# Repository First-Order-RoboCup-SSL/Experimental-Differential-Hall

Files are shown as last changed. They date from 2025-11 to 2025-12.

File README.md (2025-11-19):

# Experimental-Differential-Hall

PCB files for an experimental differential (dual) Hall element sensor. This PCB will attach to an STM32 which will perform processing on the output signals, so this PCB takes the Hall elements' output and ensures that the swing will use the maximum part of the 0-3V3 the STM32 can accept for SNR.

Still need to minimise resistors and power usage around our 5(?)% tolerance for resistors and then route PCB, but the amplifier (assuming $\pm$ 370mV around "ground" (2V) seems to work in LTSpice.

Takes in 3V3, GND, and 5V because the Hall element AFAIK wants $\pm$ 2V around "GND".

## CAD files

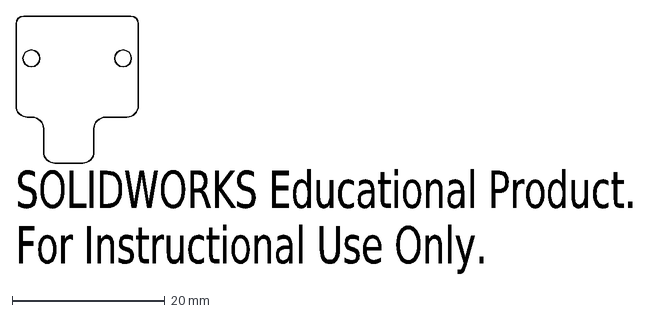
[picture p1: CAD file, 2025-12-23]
ancillary/Hall Sensor Edge Cuts 3.DXF
SOLIDWORKS Educational Product.
For Instructional Use Only.

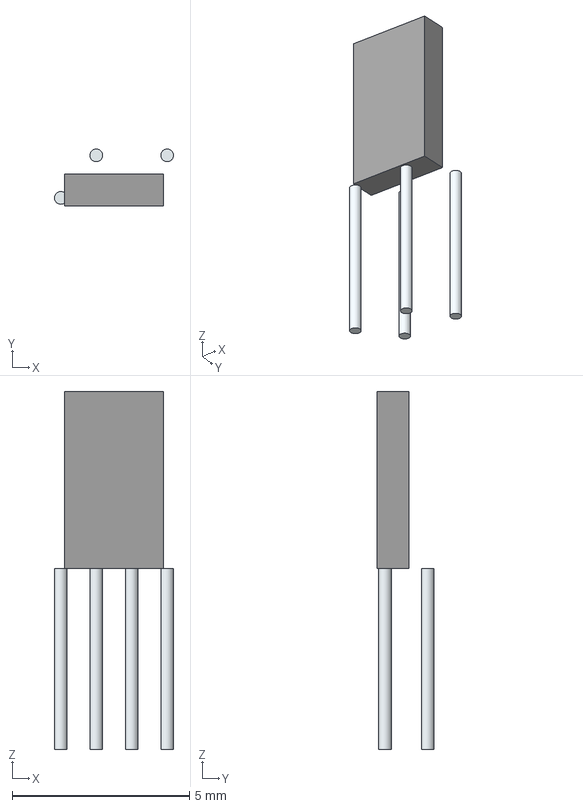
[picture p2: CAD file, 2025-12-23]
kicad/common/components/LIB_AHE300G-PA4-B/AHE300G-PA4-B/3D/AHE300G-PA4-B.stp
3.36 x 1.61 x 10.1 mm
Leads

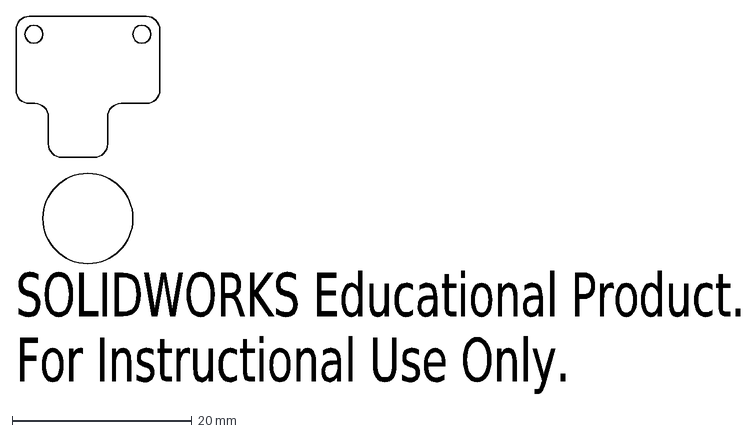
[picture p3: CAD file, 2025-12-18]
ancillary/Hall Sensor Edge Cuts 2.DXF
SOLIDWORKS Educational Product.
For Instructional Use Only.

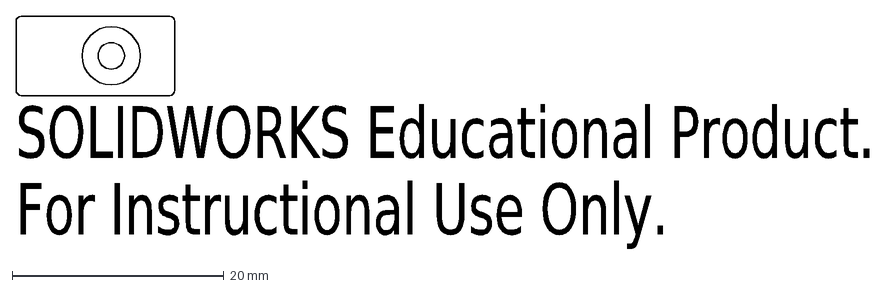
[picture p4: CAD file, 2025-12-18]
ancillary/Hall Sensor Edge Cuts 1.DXF
SOLIDWORKS Educational Product.
For Instructional Use Only.

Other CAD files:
kicad/common/components/LIB_AHE300G-PA4-B/AHE300G-PA4-B/Allegro/ahe300gpa4b.psm
kicad/common/components/LIB_AHE300G-PA4-B/AHE300G-PA4-B/DEHDL/ahe300g_pa4_b/chips/chips.prt

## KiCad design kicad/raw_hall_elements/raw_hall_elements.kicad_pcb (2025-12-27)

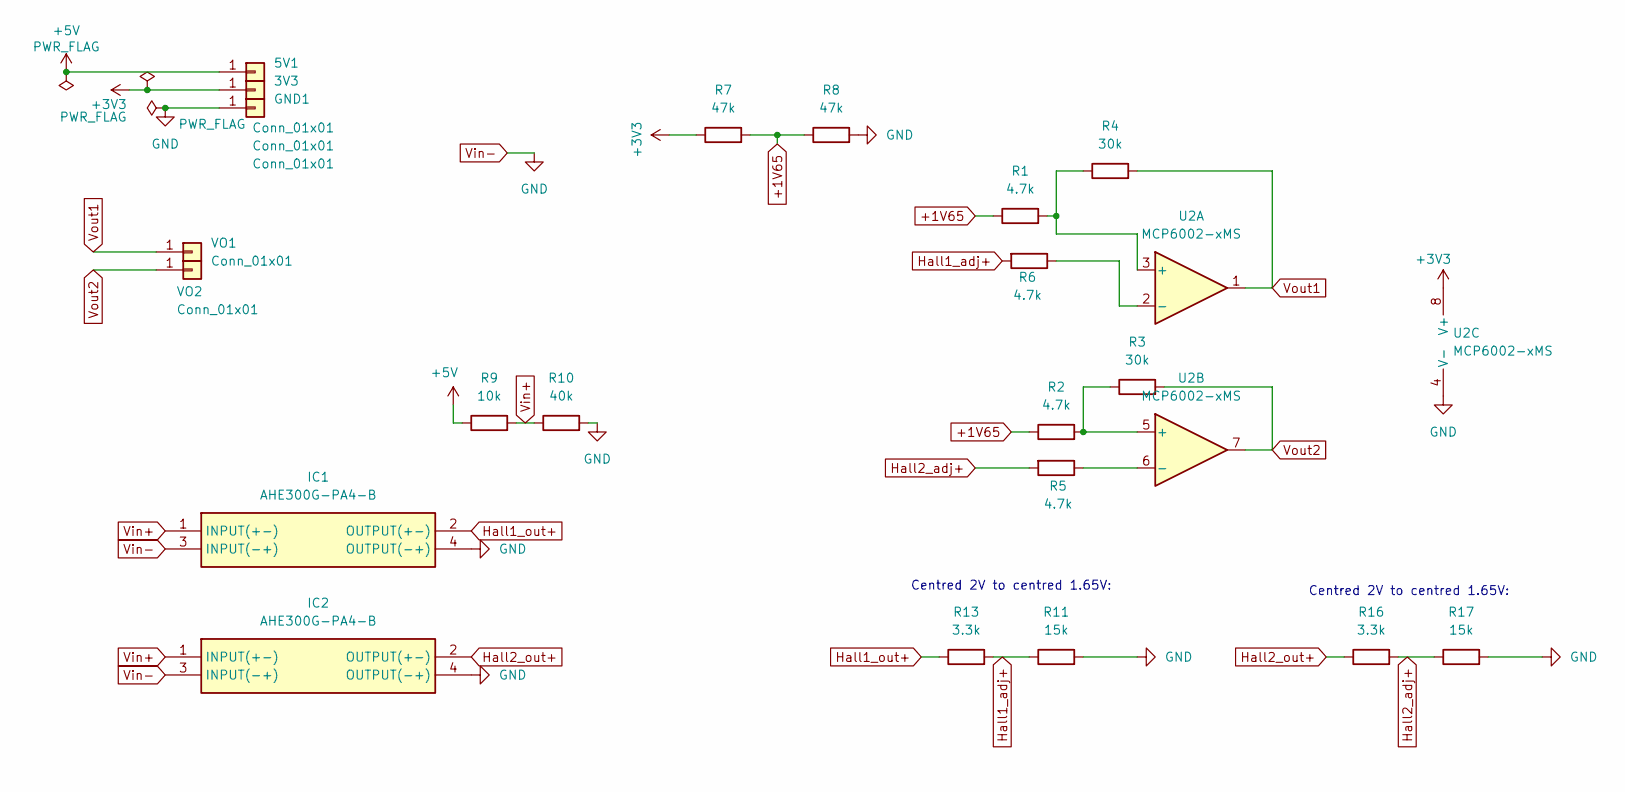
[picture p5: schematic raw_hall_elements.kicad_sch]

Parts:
3V3, 5V1: Conn_01x01; TestPoint_THTPad_1.5x1.5mm_Drill0.7mm
GND1: Conn_01x01; TestPoint_THTPad_1.5x1.5mm_Drill0.7mm
IC1, IC2: AHE300G-PA4-B; AHE300GPA4B; Manufacturer_Part_Number AHE300G-PA4-B
R1, R2, R5, R6: 4.7k; R_0603_1608Metric
R3, R4: 30k; R_0603_1608Metric
R7, R8: 47k; R_0603_1608Metric
R9: 10k; R_0603_1608Metric
R10: 40k; R_0603_1608Metric
R11, R17: 15k; R_0603_1608Metric
R13, R16: 3.3k; R_0603_1608Metric
U2: MCP6002-xMS; MSOP-8_3x3mm_P0.65mm
VO1, VO2: Conn_01x01; TestPoint_THTPad_1.5x1.5mm_Drill0.7mm

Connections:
+1V65: R1.1, R2.1, R7.2, R8.1
+3V3: 3V3.1, R7.1, U2.8 (V+)
+5V: 5V1.1, R9.1
Hall1_adj+: R6.2, R11.1, R13.2
Hall1_out+: IC1.2 (OUTPUT(+-)), R13.1
Hall2_adj+: R5.2, R16.2, R17.1
Hall2_out+: IC2.2 (OUTPUT(+-)), R16.1
unnamed: R1.2, R4.1, U2.3 (+)
unnamed: R6.1, U2.2 (-)
unnamed: R2.2, R3.1, U2.5 (+)
unnamed: R5.1, U2.6 (-)
Vin+: IC1.1 (INPUT(+-)), IC2.1 (INPUT(+-)), R9.2, R10.1
Vin-: GND1.1, IC1.3 (INPUT(-+)), IC1.4 (OUTPUT(-+)), IC2.3 (INPUT(-+)), IC2.4 (OUTPUT(-+)), R8.2, R10.2, R11.2, R17.2, U2.4 (V-)
Vout1: R4.2, U2.1, VO1.1
Vout2: R3.2, U2.7, VO2.1

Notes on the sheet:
Centred 2V to centred 1.65V:

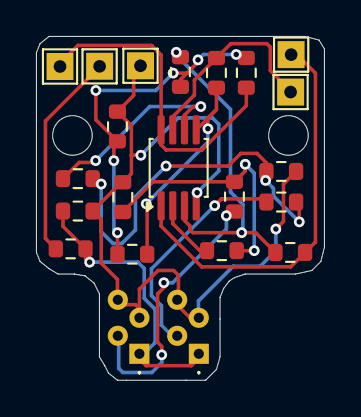
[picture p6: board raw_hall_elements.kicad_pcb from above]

Board: 2 copper layers, 16.0 x 19.1 mm, 22 parts (0 on the bottom side), 15 nets.

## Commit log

2025-11-19 initial with current kicad work
    [raw_hall_elements.kicad_pcb, raw_hall_elements.kicad_sch]
2025-12-18 Schematic now uses smaller opamp
    [Hall Sensor Edge Cuts 1.DXF, Hall Sensor Edge Cuts 2.DXF, raw_hall_elements.kicad_pcb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]
2025-12-23 more progress
    [AHE300G-PA4-B.stp, EDI2CAP.CFG, ahe300gpa4b.psm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]
2025-12-23 more progress 2
    [Hall Sensor Edge Cuts 3.DXF, raw_hall_elements.kicad_pcb]
2025-12-24 one more trace ahhhhh
    [raw_hall_elements.kicad_pcb, raw_hall_elements.kicad_sch]
2025-12-25 schematic clean up and layout finalise
    [raw_hall_elements.kicad_pcb, raw_hall_elements.kicad_sch]
2025-12-27 clean up schematic, finish layout and sent for manuf
    [raw_hall_elements.kicad_pcb]
